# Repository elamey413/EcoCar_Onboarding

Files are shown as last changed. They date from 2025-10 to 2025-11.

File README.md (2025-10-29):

Hello! This is my onboardind project for the UAlberta club EcoCar. It contains an STM32F103C8T6 based PCB with an IMU, CAN transciever, thermocouple, and pressure sensor. It also has an OLED display to show all the amazing data you can collect
with the board. Please Download the Onboarding- Copy file to access the schematic and PCB model.

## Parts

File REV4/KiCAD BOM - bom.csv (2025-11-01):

Designator | Footprint | Quantity | Value | LCSC Part #
120R1 | LairdTech_28C0236-0JW-10 | 1 | FerriteBead 120R
C1, C2 | 805 | 2 | 22u
C10, C9 | 805 | 2 | 1u
C11, C12, C13_2, C13, C14, C15, C16, C4, C5, C6, C7 | 805 | 11 | 100n
C3 | 805 | 1 | 10u
C8 | 805 | 1 | 10n
D1 | 805 | 1 | LED
D2,D3,D4 | 603 | 3 | LED_R
J2 | USB_C_Receptacle_Palconn_UTC16-G | 1 | USB_C_Receptacle_USB2.0_16P
R1, R10, R11, R4, R5, R6, R7 | 805 | 7 | 1k5
R12 | 805 | 1 | 120
R2, R3 | 805 | 2 | 10k
R8, R9 | 805 | 2 | 5k1
SW1 | SW_PUSH_6mm | 1 | SW_PUSH_6mm
SW2 | SW_SPDT_CK_JS102011SAQN | 1 | SW_SPDT
TH1 | LED_D4.0mm | 1 | 10K, RL0503-5820-97-MS | https://www.digikey.ca/en/products/detail/amphenol-advanced-sensors/RL0503-5820-97-MS/136365
U1 | SOT-223-3_TabPin2 | 1 | AMS1117-3.3
U3 | HLGA-10L_2X2X0P73_STM | 1 | BME280
U5 | SOIC8_4P9X3P9MC_MCH | 1 | MCP2542FD
Y1 | Oscillator_SMD_TXC_7C-4Pin_5.0x3.2mm | 1 | OT32258MJBA4SL
Parts On hand
U2 | LQFP-48_7x7mm_P0.5mm | 1 | STM32F103C8T6
U4 | None | 1 | IMU GY 521
U6 |  | 1 | NHD-C0220BIZ

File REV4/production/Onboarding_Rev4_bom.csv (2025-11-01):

Designator | Footprint | Quantity | Value | LCSC Part #
120R1 | LairdTech_28C0236-0JW-10 | 1 | FerriteBead
C1, C2 | 0805 | 2 | 22u
C10, C9 | 0805 | 2 | 1u
C11, C12, C13_2, C13, C14, C15, C16, C4, C5, C6, C7 | 0805 | 11 | 100n
C3 | 0805 | 1 | 10u
C8 | 0805 | 1 | 10n
D1 | 0805 | 1 | LED
D2 | 0603 | 1 | LED_R
D3 | 0603 | 1 | LED_G
D4 | 0603 | 1 | LED_B
J1, J3, J5 | Conn_01x04_pin | 3 | Conn_01x04_Socket
J2 | USB_C_Receptacle_Palconn_UTC16-G | 1 | USB_C_Receptacle_USB2.0_16P
R1, R10, R11, R4, R5, R6, R7 | 0805 | 7 | 1k5
R12 | 0805 | 1 | 120
R2, R3 | 0805 | 2 | 10k
R8, R9 | 0805 | 2 | 5k1
SW1 | SW_PUSH_6mm | 1 | SW_PUSH_6mm
SW2 | SW_SPDT_CK_JS102011SAQN | 1 | SW_SPDT
TH1 | LED_D4.0mm | 1 | 10K
U1 | SOT-223-3_TabPin2 | 1 | AMS1117-3.3
U2 | LQFP-48_7x7mm_P0.5mm | 1 | STM32F103C8T6
U3 | HLGA-10L_2X2X0P73_STM | 1 | BME280
U5 | SOIC8_4P9X3P9MC_MCH | 1 | MCP2542FD
Y1 | Oscillator_SMD_TXC_7C-4Pin_5.0x3.2mm | 1 | OT32258MJBA4SL

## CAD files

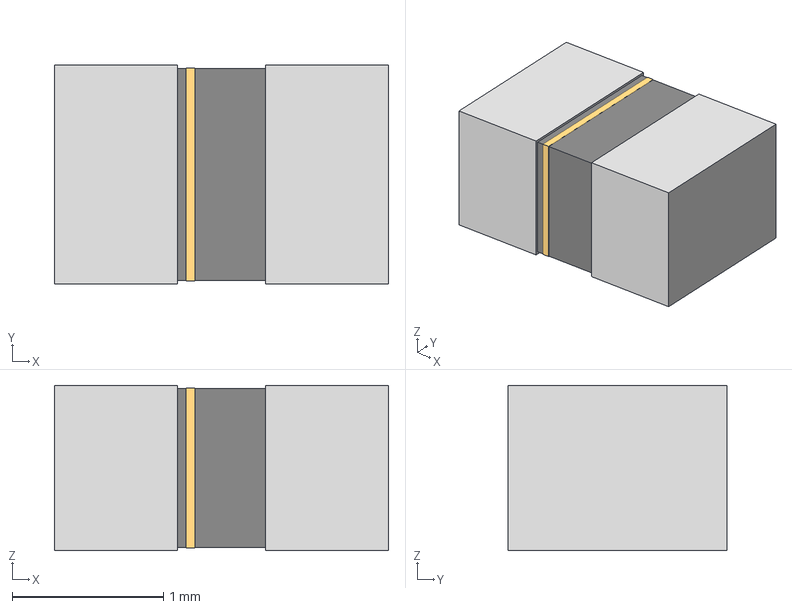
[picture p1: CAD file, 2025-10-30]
2508051217Y6/IND_25_0805_FRT.iges
2.21 x 1.45 x 1.09 mm

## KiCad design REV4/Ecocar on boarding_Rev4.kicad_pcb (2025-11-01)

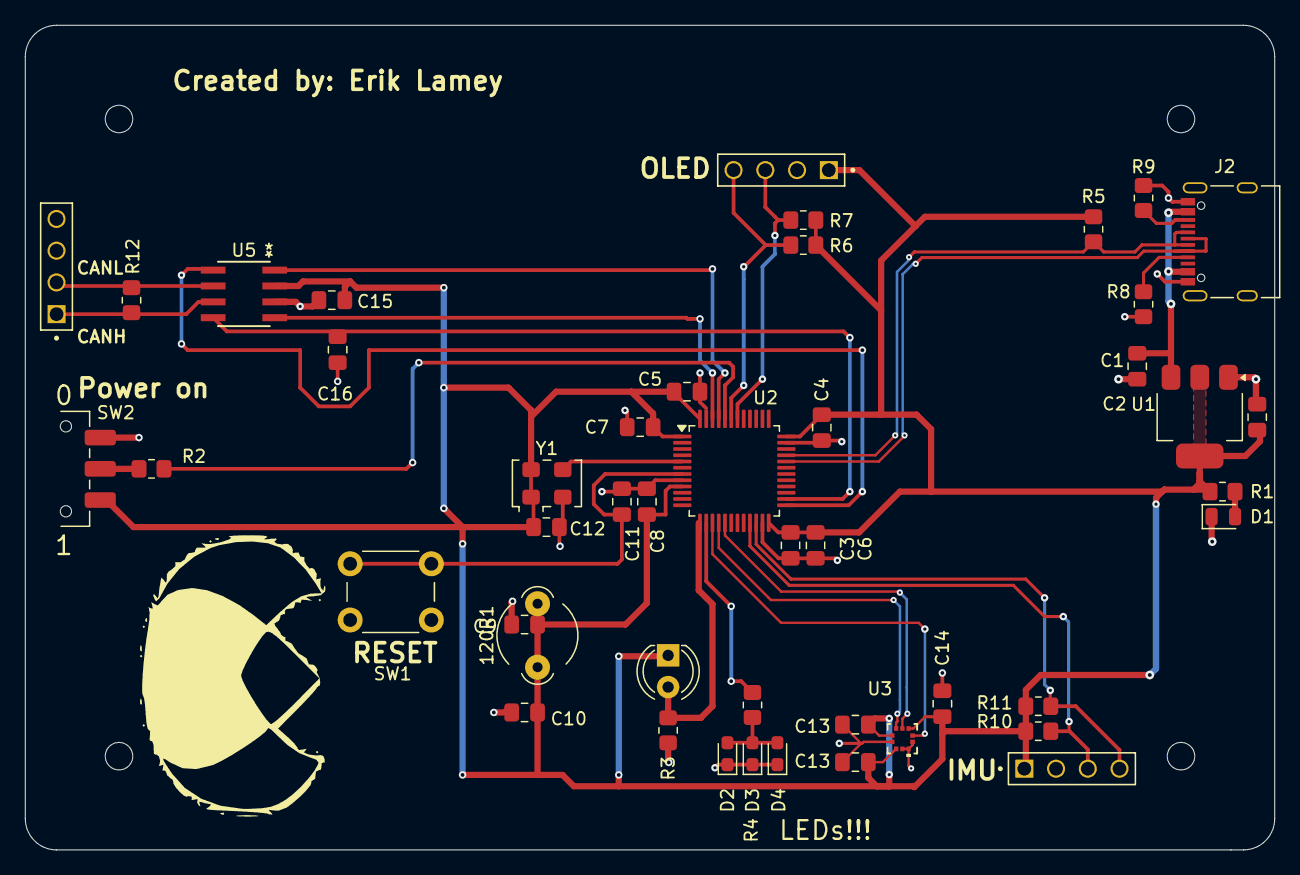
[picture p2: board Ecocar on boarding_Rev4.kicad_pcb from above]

Board: 2 copper layers, 100.0 x 66.0 mm, 50 parts (0 on the bottom side), 29 nets.

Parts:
120R1: FerriteBead; LairdTech_28C0236-0JW-10
C1, C2: 22u; C_0805_2012Metric_Pad1.18x1.45mm_HandSolder
C3: 10u; C_0805_2012Metric_Pad1.18x1.45mm_HandSolder
C4, C5, C6, C7, C11, C12, C13, C13#2, C14, C15, C16: 100n; C_0805_2012Metric_Pad1.18x1.45mm_HandSolder
C8: 10n; C_0805_2012Metric_Pad1.18x1.45mm_HandSolder
C9, C10: 1u; C_0805_2012Metric_Pad1.18x1.45mm_HandSolder
D1: LED; LED_0805_2012Metric
D2: LED_R; LED_0603_1608Metric_Pad1.05x0.95mm_HandSolder
D3: LED_G; LED_0603_1608Metric_Pad1.05x0.95mm_HandSolder
D4: LED_B; LED_0603_1608Metric_Pad1.05x0.95mm_HandSolder
H1, H2, H3, H4: MountingHole; MountingHole_2.2mm_M2
J1, J3, J5: Conn_01x04_Socket; Conn_01x04_pin
J2: USB_C_Receptacle_USB2.0_16P; USB_C_Receptacle_Palconn_UTC16-G
R1, R4, R5: 1k5; R_0805_2012Metric_Pad1.20x1.40mm_HandSolder
R2: 10k; R_0805_2012Metric_Pad1.20x1.40mm_HandSolder
R3: 10K; R_0805_2012Metric_Pad1.20x1.40mm_HandSolder
R6, R7, R10, R11: 1K5; R_0805_2012Metric_Pad1.20x1.40mm_HandSolder
R8, R9: 5k1; R_0805_2012Metric_Pad1.20x1.40mm_HandSolder
R12: 120; R_0805_2012Metric_Pad1.20x1.40mm_HandSolder
SW1: SW_PUSH_6mm
SW2: SW_SPDT; SW_SPDT_CK_JS102011SAQN
TH1: 10K; LED_D4.0mm
U1: AMS1117-3.3; SOT-223-3_TabPin2
U2: STM32F103C8T6; LQFP-48_7x7mm_P0.5mm
U3: BME280; HLGA-10L_2X2X0P73_STM
U5: MCP2542FD; SOIC8_4P9X3P9MC_MCH
Y1: OT32258MJBA4SL; Oscillator_SMD_TXC_7C-4Pin_5.0x3.2mm

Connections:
+3.3VA: 120R1.2, C8.1, C9.1, U2.9 (VDDA)
+3V3: 120R1.1, C2.1, C3.1, C4.1, C5.1, C6.1, C7.1, C10.1, C12.1, C13.1, C13#2.1, C14.1, C15.1, J1.01, J3.01, R1.1, R5.1, R6.1, R7.1, R10.1, R11.1, SW2.3 (C), TH1.1, U1.2 (VO), U2.1 (VBAT), U2.24 (VDD), U2.36 (VDD), U2.48 (VDD), U3.3 (SDI), U3.6 (VDDIO), U3.8 (VDD), U5.3 (VCC), Y1.1 (EN), Y1.4 (Vdd)
/BOOT0: R2.2, U2.44 (BOOT0)
/CANH: J5.01, R12.1, U5.7 (CANH)
/CANL: J5.02, R12.2, U5.6 (CANL)
/CAN_RX: U2.45 (PB8), U5.4 (RXD)
/CAN_TX: U2.46 (PB9), U5.1 (TXD)
/CC1: J2.A5 (CC1), R8.1
/CC2: J2.B5 (CC2), R9.1
/HSE_in: U2.5 (PD0), Y1.3 (OUT)
/I2C1_SCL_OLED: J1.03, R7.2, U2.42 (PB6)
/I2C1_SDA_OLED: J1.04, R6.2, U2.43 (PB7)
/I2C2_SCL_IMU: J3.03, R10.2, U2.21 (PB10)
/I2C2_SDA_IMU: J3.04, R11.2, U2.22 (PB11)
/NRST: C11.1, SW1.1, U2.7 (NRST)
/PWR_LED_K: D1.2 (A), R1.2
/SPI_MISO: U2.16 (PA6), U3.5 (SDO)
/SPI_MOSI: U2.17 (PA7), U3.4 (SCK)
/SPI_SCK: U2.15 (PA5), U3.2 (CSB)
/STBY: U2.25 (PB12), U5.5 (SHDN)
/STD: C16.1, U2.26 (PB13), U5.8 (STD)
/SW_BOOT0: R2.1, SW2.2 (B)
/USB_D+: J2.A6 (D+), J2.B6 (D+), R5.2, U2.33 (PA12)
/USB_D-: J2.A7 (D-), J2.B7 (D-), U2.32 (PA11)
GND: C1.2, C2.2, C3.2, C4.2, C5.2, C6.2, C7.2, C8.2, C9.2, C10.2, C11.2, C12.2, C13.2, C13#2.2, C14.2, C15.2, C16.2, D1.1 (K), D2.1 (K), D3.1 (K), D4.1 (K), J1.02, J2.A1 (GND), J2.A12 (GND), J2.B1 (GND), J2.B12 (GND), J3.02, R3.2, R8.2, R9.2, SW1.2, SW2.1 (A), U1.1 (GND), U2.8 (VSSA), U2.23 (VSS), U2.35 (VSS), U2.47 (VSS), U3.1 (GND), U3.7 (GND), U3.9 (GND), U3.10 (GND), U5.2 (GND), Y1.2 (GND)
unnamed: D2.2 (A), D3.2 (A), D4.2 (A), R4.1
unnamed: R3.1, TH1.2, U2.13 (PA3)
unnamed: R4.2, U2.14 (PA4)
VBUS: C1.1, J2.A4 (VBUS), J2.A9 (VBUS), J2.B4 (VBUS), J2.B9 (VBUS), U1.3 (VI)

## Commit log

2025-10-25 Pushing KiCAD file v1
    [Ecocar on boarding.kicad_pcb, Ecocar on boarding.kicad_sch]
2025-10-25 Pushing Onboarding V2
    [Ecocar on boarding.kicad_pcb, Ecocar on boarding.kicad_sch]
2025-10-29 Revision 2 upload
    [Ecocar on boarding.kicad_pcb, Ecocar on boarding.kicad_sch]
2025-10-30 Revision 3 Upload
    [Ecocar on boarding Rev3.kicad_sch, Ecocar on boarding_Rev3.kicad_pcb, IND_25_0805_FRT.iges]
2025-11-01 Revision 4 upload
    [Ecocar on boarding_Rev4.kicad_pcb, Ecocar on boarding_Rev4.kicad_sch, Onboarding_Rev4_bom.csv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]
2025-11-01 Complete Bom upload
    [KiCAD BOM - bom.csv]
